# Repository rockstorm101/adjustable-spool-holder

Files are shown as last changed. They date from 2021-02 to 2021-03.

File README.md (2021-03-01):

# Adjustable Spool Holder

Spool holder which adapts to different widths and diameters of
filament spools while providing a smooth rolling experience on all
cases.

## Bill of Materials

Part Number | Description  | Quantity
   :---     |     :---     |  :---:
291010      | Screw        |    1
6905-ZZ     | Bearing      |    2
291110      | Clamp        |    2
291210      | Nut, Bearing |    1
291310      | Nut          |    1

This holder is designed to use bearings of size 42x25x9
(6905-xx). Same bearings but with different shields/seals
(i.e. 6905-2RS) should work too. For this type of application any
bearing quality would do.

## Print Settings
### Screw (2910)
- Rafts: No
- Supports: Yes
- Resolution:
  - <= 0.1 mm on the coupling ramp (start Z: 2.8 mm, finish Z: 3.8 mm)
  - <= 0.1 mm on the threaded section (start Z: 41.0 mm, finish Z: 136.6 mm)
  - Any layer height elsewhere (I used 0.2 mm)
- Infill: >= 50%
- Vertical Shells: 3

### Clamp (2911)
- Rafts: No
- Supports: No
- Resolution: Any (I used 0.2 mm)
- Infill: >= 50%
- Vertical Shells: 3

### Nut, Bearing (2912)
- Rafts: No
- Supports: No
- Resolution: <= 0.1 mm
- Infill: >= 20%
- Vertical Shells: 3

### Nut (2913)
- Rafts: No
- Supports: No
- Resolution: <= 0.1 mm
- Infill: >= 20%
- Vertical Shells: 3

## Customise / Compile / Build
### Build STL files

Generate the intermediate SCAD file with the following command. Replace
<...> with the relevant file/name on each case. With no other parameters
this will generate a file called `<source_file>.scad`.
```
python <source_file>.py
```

Generate the STL file with:
```
openscad -o <stl_file>.stl <source_file>.scad
```

### Requirements
- [SolidPython][6]: a python front-end for solid modelling to OpenSCAD
- [OpenSCAD][7]: a solid 3D CAD modeller
- [Custom MCAD][8]: customised version of the MCAD library ('more-dev' branch)
- The [Open Sans][9] font (paticularly the "Bold" style)

[6]: https://github.com/SolidCode/SolidPython
[7]: http://www.openscad.org
[8]: https://github.com/rockstorm101/MCAD/tree/more-dev
[9]: https://www.1001freefonts.com/open-sans.font

## Assembly

See images on `doc/images`. Orientation of the Clamps and the Nut are
critical. Clamps contact the bearings on their outer race and the
Screw and Nut contact the bearings on their inner race. It is critical
that these contacts occur on opposite sides of the bearings.

## Credits

The end coupling to be able to use the original nut from an Ender 3
spool holder is taken from [Ender 3 spool holder][1] by [@emolan][2].

[1]: https://www.thingiverse.com/thing:3979065
[2]: https://www.thingiverse.com/emolan

The font used for engraving is [Open Sans][9] by Steve Matteson.

## License

[CC BY-SA 4.0][4]

```
Copyright (c) 2021 Rock Storm

This work is open source hardware: you can redistribute it and/or modify
it under the terms of the Attribution-ShareAlike 4.0 International.

The code generating the models is distributed under the GNU General
Public License as published by the Free Software Foundation, either
version 3 of the License, or (at your option) any later version.

This work is distributed in the hope that it will be useful, but WITHOUT
ANY WARRANTY; without even the implied warranty of MERCHANTABILITY or
FITNESS FOR A PARTICULAR PURPOSE.
```

[3]: https://licensebuttons.net/l/by-sa/4.0/88x31.png
[4]: https://creativecommons.org/licenses/by-sa/4.0/
[5]: https://i1.wp.com/www.oshwa.org/wp-content/uploads/2014/03/oshw-logo-100-px.png

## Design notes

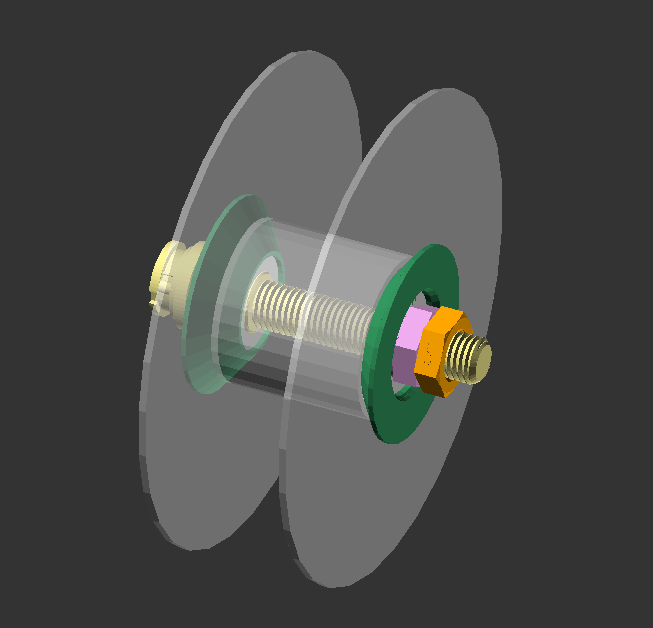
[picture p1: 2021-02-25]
doc/images/main_view.png

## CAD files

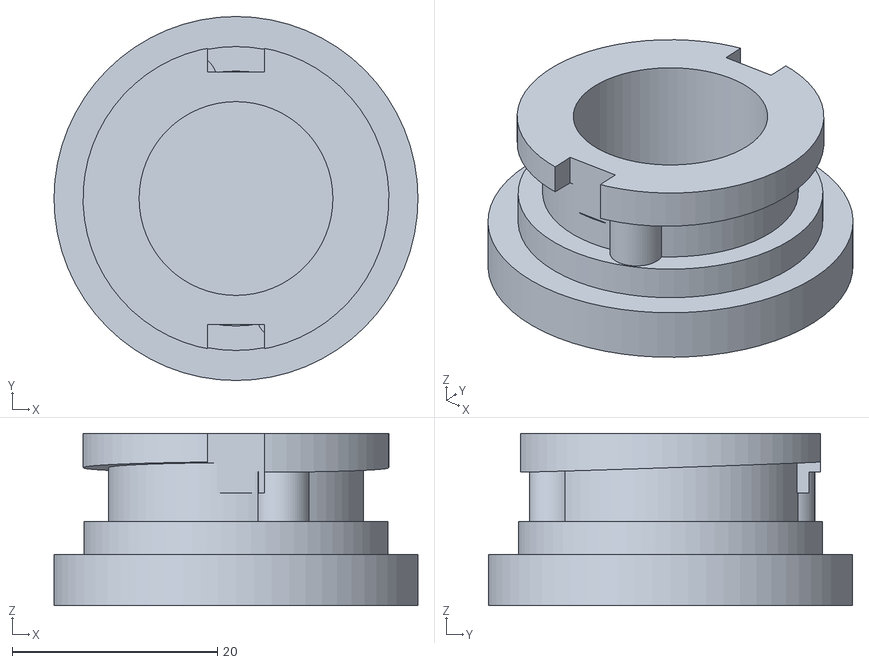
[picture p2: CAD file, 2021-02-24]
aux/Ender_3_spool_holder/Ender3_Spool_Holder_Coupling.stl
35.5 x 35.5 x 16.8

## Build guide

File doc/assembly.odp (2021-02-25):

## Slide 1

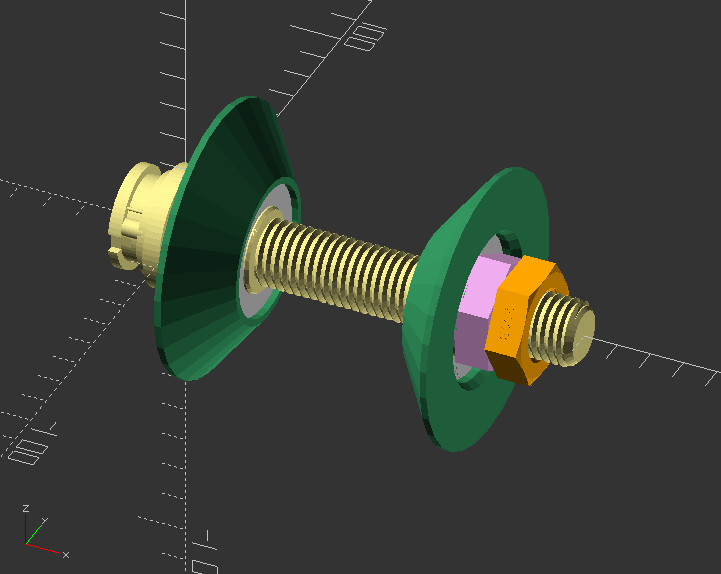
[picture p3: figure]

3

1

2

2

5

1. Screw
2. Bearing
3. Clamp
4. Nut, Bearing
5. Nut

4

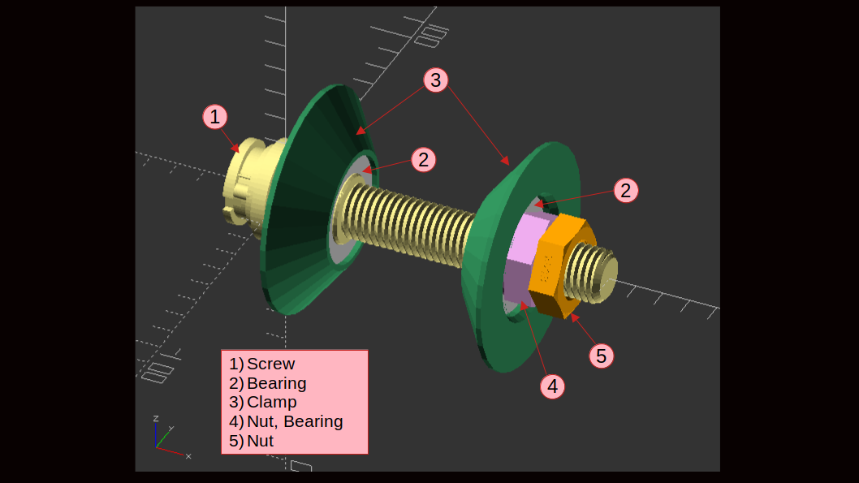
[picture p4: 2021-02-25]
doc/images/assembly_overview.png

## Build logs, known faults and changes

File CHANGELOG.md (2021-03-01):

# Changelog

## 1.0

First production release.

### Added

- p11: Added engraved P/N
- p10: Thread clearance set at a final +/- 0.5 mm

## 0.2

### Added

- p13: Added counter-nut
- p10: Thread enlarged by 10 mm
- p10: Added engraved P/N
- p10/12: Lead-in chamfers on bearing seats

### Fixed

- p12: Fixed conflicting part description
- p10: Ender 3 coupling scaled down by 0.2 mm
- p10: Thread clearance increased to 0.7 mm

## 0.2-p1

### Fixed

- p10: Thread clearance increased to 0.6 mm
- Versioning corrected

## 0.1-p9

### Fixed

- p10: Thread clearance increased to 0.4 mm

## 0.1-p8

Screw broke due to excessive torque tightening.

### Added

- Added male thread prototype (m02)
- Assembly documentation (images)
- p10: Extended Screw by 20 mm
- Added argument parsing to all sources
- Added a filament spool mockup (m01)
- p12: Changed size and font of scribed P/N

### Fixed

- 2910: Fixed Screw not using thread clearance parameter
- Removed unused functions (which are now ported to MCAD)

## 0.1

### Added

- Thread clearance reduced to 0.3 mm
- Added nut-like feature and scribed P/N to Nut (2912)
- Sharp edges removed and added lead-in chamfer to Clamp (2911)
- GA (2900) generates BoM

### Fixed

- Connector calls/naming
- Fixed 'debug' parameter call on GA (2900)

## 0.1-p7 - Thread Fit Test
- Updated MCAD file to produce threads
- Thread clearances: 0.4 mm on both male and female
- g1: layer height 0.2 mm
- g2: layer height 0.1 mm on threaded areas

## 0.1-p6 - Thread Fit Test
- Thread clearances: -0.5 on male and +0.5 on female.
- Thread printed at 0.1 layer height.
- Using version 2.5 of threads file

## 0.1-p2 - Coupling Fit Test
- Ramp printed a 0.1 mm layer height
- Supports everywhere

## 0.1-p1 - Thread Fit Test
 - Using version 1.3 of threads file

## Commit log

2021-01-24 Commit first working prototype
2021-01-31 Add male thread prototype
2021-02-10 Add BoM and rearrange GA
2021-02-10 p2912: Add nut-like feature and P/N
2021-02-11 v2901: Fix wrong connector call
2021-02-11 p2910: Fix connector call and tidy up comments
2021-02-11 p2910: Reduce thread clearance
2021-02-13 p2910: Long screw, add argparse and fix clearance
2021-02-13 p2911: Add argparse and connector for a spool
2021-02-13 v2901: Add argparse and debug connector
2021-02-13 d/images: Add general and assembly views
2021-02-19 m02: Add model for male thread prototype
2021-02-20 p10: Increase male thread clearance to 0.4
2021-02-20 p10: Increase male thread clearance to 0.6 mm
2021-02-20 p10: Increase male thread clearance to 0.7 mm
    Current female thread seems to have 0.3 mm clearance. Therefore +/-0.5
    seems to work.
2021-02-24 p12: Add lead-in chamfer for bearing
2021-02-24 Only .gitignore STL files in src folder
2021-02-24 Clean up Ender 3 spool holder folder
    [Ender3_Spool_Holder_Coupling.stl]
2021-02-24 p10: Update to coupling new location
2021-02-24 p10/p12: Unifiy bearing seat definition
2021-02-24 p12: Abstract hexagon and thread functions
2021-02-25 p10: Enlarge thread and deepen P/N
2021-02-25 p12: Correct thread chamfers
2021-02-25 p13: Add counter-nut part
2021-02-25 a00: Add counter-nut to the assembly
2021-03-01 p10: Set thread clearance to final +/-0.5 mm
2021-03-01 readme: Fix and add missing print settings
